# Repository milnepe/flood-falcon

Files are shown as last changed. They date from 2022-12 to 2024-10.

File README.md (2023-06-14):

# Flood Falcon & Flood Magnet
Arduino powered flood warning devices

Flood Magnet
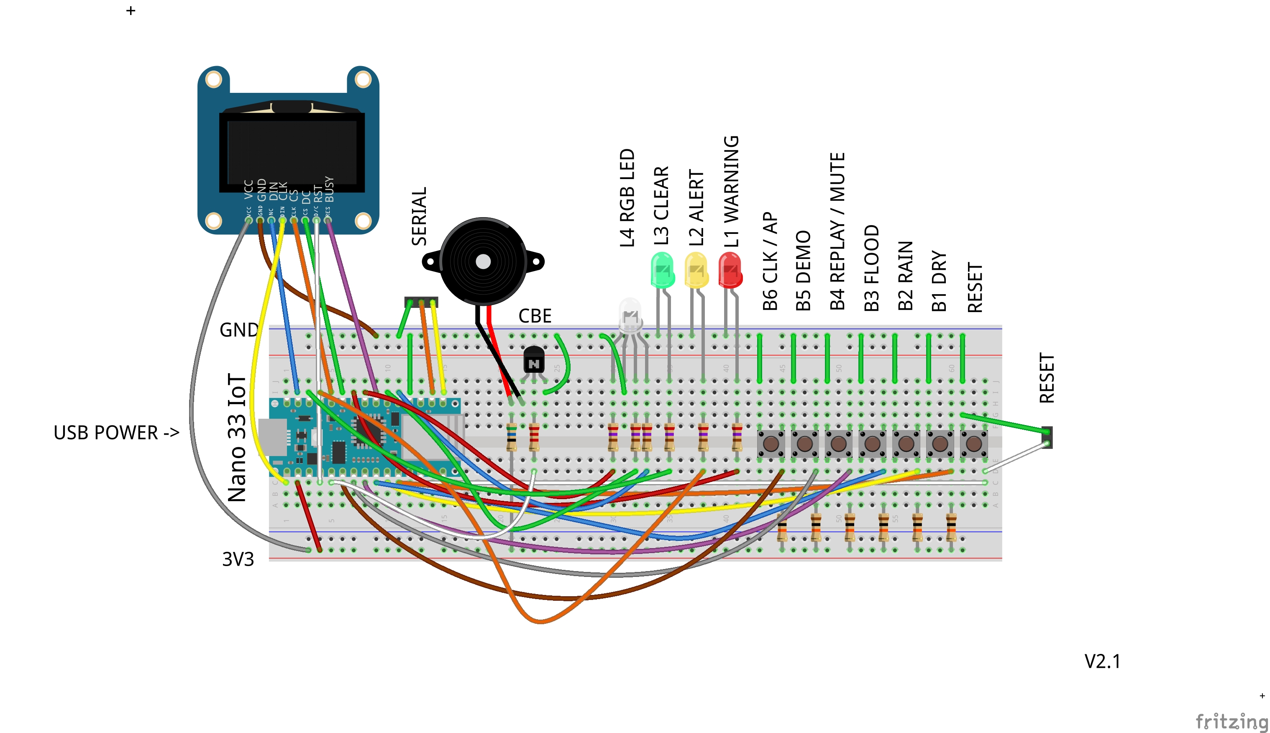
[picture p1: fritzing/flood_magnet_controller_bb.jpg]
Flood Magnet Circuit Diagram
.

## Introduction
The Environment Agency flood-monitoring API provides developers with access to near real time information covering:

- Flood warnings and flood alerts
- Flood areas which to which warnings or alerts apply
- Measurements of water levels and flows
- Information on the monitoring stations providing those measurements

Water levels and flows are regularly monitored, usually every 15 minutes. However, data is transferred back to the Environment Agency at various frequencies, usually depending on the site and level of flood risk. Transfer of data is typically once or twice per day, but usually increases during times of heightened flood risk.

These APIs are provided as open data under the Open Government Licence with no requirement for registration. If you make use of this data please acknowledge this with the following attribution statement:

"this uses Environment Agency flood and river level data from the real-time data API (Beta)"

## Getting your flood warning area
This is the easiest way to find out your flood area but there needs to be an alert or warning at the time:

You can get all the flood warnings in the UK in you browser by visiting the following URL:
[Flood alerts and warnings](https://check-for-flooding.service.gov.uk/alerts-and-warnings)

Click on the warning you are interested in for example Keswick Campsite:
[https://check-for-flooding.service.gov.uk/target-area/011FWFNC6KC](https://check-for-flooding.service.gov.uk/target-area/065WAF441)

The last part of the URL above is the flood warning area code in this example it is 011FWFNC6KC

If there is no flood warning for your area you can find the url from your Lat / Long coordinates.
For example Witney in Oxfordshire has lat: 51.7859° N, long: 1.4851° W
North is positive, West is negative.

Put these into the following URL 

http://environment.data.gov.uk/flood-monitoring/id/floodAreas?lat=y&long=x&dist=d

Where: y is the lat, x is the long and d is the distance in km from your location. Start with close distances and use larger values if you don't get any results.

So for Witney the URL is (Note the negative W coordinate):
https://environment.data.gov.uk/flood-monitoring/id/floodAreas?lat=51.7859&long=-1.4851&dist=0.5

Paste this into a browser and you will get a list of possible Flood Areas. Here's the result for Witney:
```
  "items" : [ { 
    "@id" : "http://environment.data.gov.uk/flood-monitoring/id/floodAreas/061FWF10Witney" ,
    "county" : "Oxfordshire" ,
    "description" : "River Windrush at Witney and Ducklington down to and including Hardwick" ,
    "eaAreaName" : "Thames" ,
    "floodWatchArea" : "http://environment.data.gov.uk/flood-monitoring/id/floodAreas/061WAF10Windrush" ,
    "fwdCode" : "061FWF10Witney" ,
    "label" : "River Windrush at Witney and Ducklington" ,
    "lat" : 51.75773 ,
    "long" : -1.45314 ,
    "notation" : "061FWF10Witney" ,
    "polygon" : "http://environment.data.gov.uk/flood-monitoring/id/floodAreas/061FWF10Witney/polygon" ,
    "quickDialNumber" : "171073" ,
    "riverOrSea" : "River Windrush"
  }
  , { 
    "@id" : "http://environment.data.gov.uk/flood-monitoring/id/floodAreas/061WAF10Windrush" ,
    "county" : "Gloucestershire, Oxfordshire" ,
    "description" : "River Windrush from Bourton to Newbridge including Burford, Asthall, Minster Lovell, Crawley, Witney, Ducklington, Rack End and Standlake" ,
    "eaAreaName" : "Thames" ,
    "fwdCode" : "061WAF10Windrush" ,
    "label" : "River Windrush from Bourton to Newbridge" ,
    "lat" : 51.82888 ,
    "long" : -1.65351 ,
    "notation" : "061WAF10Windrush" ,
    "polygon" : "http://environment.data.gov.uk/flood-monitoring/id/floodAreas/061WAF10Windrush/polygon" ,
    "quickDialNumber" : "171075" ,
    "riverOrSea" : "River Windrush"
  }
...
```
Use the "description" key to find the nearest area to you and then take the "@id" url for that area. For example:
"@id" : "http://environment.data.gov.uk/flood-monitoring/id/floodAreas/061FWF10Witney"

Now take the last part of the "@id" url which is the key for that area, in this case "061FWF10Witney"

Copy and paste the key into the magnet_config.h file:
```
// Your flood area code from Gov.co.uk Flood Warning Service
#define AREA_CODE "061FWF10Witney"
```

## Testing
You can test the API for your flood area by making a request in your browser to the following URI:
http://environment.data.gov.uk/flood-monitoring/id/floods/{your-flood-area-code}

So in the example above for the Witney use this URI:
[https://check-for-flooding.service.gov.uk/target-area/061FWF10Witney](https://check-for-flooding.service.gov.uk/target-area/061FWF10Witney)

This will return a JSON object with all the flood information for that area.

## API Documentation:
[Flood API](http://environment.data.gov.uk/flood-monitoring/doc/reference#flood-warnings)

## Falcon display
The Falcon / Magnet polls the API at the frequency you set and it receives the API response and displays the following data:

An icon representing the flood warning which may be at one of four possible severity levels - derived from the severityLevel:

Level	Name				    Meaning
1. Severe Flood Warning		    Severe Flooding, Danger to Life.
2. Flood Warning			    Flooding is Expected, Immediate Action Required.
3. Flood Alert                  Flooding is Possible, Be Prepared.
4. Warning no Longer in Force   The warning is no longer in force

The severity level description - derived from severity

The update date / time - derived from timeRaised (The date and time the warning was last reviewed. Usually (but not always) this leads to a change in the message or severity)

## Configuration
User config is in "falcon_config.h" or "magnet_config.h" Add your WiFi details and Flood Area there.

Audio clips are in ./audio - connect your sound board to your PC and copy the clips to the mounted drive.

## Demo Mode
Hold down the Demo button and press the Reset button to enter Demo Mode. Press Reset again to exit back to Standard Mode.

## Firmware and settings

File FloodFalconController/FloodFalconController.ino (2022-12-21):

/*
  Arduino Nano 33 IoT client for Gov.co.uk Flood Warning Service

  Install the following libraries using the Arduino Libary Manager:
  Arduino WiFiNINA https://github.com/arduino-libraries/WiFiNINA
  Benoît Blanchon ArduinoJson https://arduinojson.org/
  Evert-arias EasyButton https://github.com/evert-arias/EasyButton
  Adafruit Soundboard https://github.com/adafruit/Adafruit_Soundboard_library
  Adafruit PWM Servo Driver https://github.com/adafruit/Adafruit-PWM-Servo-Driver-Library

  Author: Peter Milne
  Date: 28 Nov 2022

  Copyright 2022 Peter Milne
  Released under GNU GENERAL PUBLIC LICENSE
  Version 3, 29 June 2007
*/

#include <SPI.h>
#include <WiFiNINA.h>
#include <ArduinoJson.h>
#include <EasyButton.h>
#include "FloodFalcon.h"
#include "FloodFalconDisplay.h"

const char* soft_version = "0.2.1";

#define SERVO 0        // Flapping servo
#define SERVO_FREQ 50  // Analog servos run at ~50 Hz

#define SFX_RST 4  // Sound board RST pin

// Flood warning data
static floodWarning warning;

WiFiClient client;

// Servo board - default address 0x40
Adafruit_PWMServoDriver pwm = Adafruit_PWMServoDriver();

// Sound board connected to Serial1 - must be set to 9600 baud
Adafruit_Soundboard sfx = Adafruit_Soundboard(&Serial1, NULL, SFX_RST);

FloodFalcon myFalcon = FloodFalcon(&sfx, &pwm, &warning);

FloodFalconDisplay epd = FloodFalconDisplay(&myFalcon);

int status = WL_IDLE_STATUS;
boolean updateDisplayFlag = false;
unsigned long lastReconnectAttempt = 0;
boolean playBackFlag = false;

// Define pins
const int wifiLed = 10;  // Optional debug LED (Green - On if connected)
const int rButton = 2;
const int lButton = 3;
const int dButton = 9;

EasyButton rightButton(rButton);  // RH button
EasyButton leftButton(lButton);   // LH button
EasyButton demoButton(dButton);   // External demo button

int demo_state = NONE;

void setup() {
  pinMode(wifiLed, OUTPUT);
  digitalWrite(wifiLed, LOW);

  // Initialize Serial Port
  Serial.begin(115200);
  while (!Serial) {
    ;  // wait for serial port to connect. Needed for native USB port only
  }
  delay(2000);

  // Serial 1 used for sound board at 9600 baud
  Serial1.begin(9600);
  while (!Serial1) {
    ;  // wait for serial port to connect
  }
  Serial.print("Starting client version: ");
  Serial.println(soft_version);

  Serial.println("Serial1 attached");

  // Initialize buttons
  rightButton.begin();
  rightButton.onPressed(playback);        // Short press triggers playback
  rightButton.onPressedFor(2000, audio);  // Long press toggles audio
  leftButton.begin();
  leftButton.onPressed(demo);  // Short press for demo
  demoButton.begin();
  demoButton.onPressed(demo);  // Short press external button for demo
  // Press reset button (middle) to exit demo

  // Setup display and show greeting
  epd.initDisplay();
  epd.showGreeting();

  // Init servo
  pwm.begin();
  pwm.setOscillatorFrequency(27000000);
  pwm.setPWMFreq(SERVO_FREQ);  // Analog servos run at ~50 Hz updates
  delay(1000);

  myFalcon.init(SERVO, WINGS_DOWN);  // Set statrting posture
  myFalcon.doAction(epd.audioOn);    // Trigger intro action

  leftButton.read();
  demoButton.read();
  if (leftButton.isPressed() || demoButton.isPressed()) {
    epd.demoOn = true;
  }

  delay(12000);
}

void loop() {
  // Continuously update the button states
  rightButton.read();
  leftButton.read();
  demoButton.read();

  if (!epd.demoOn) {  // Standard mode
    if (WiFi.status() != WL_CONNECTED) {
      // Connect wifi if it's not connected
      digitalWrite(wifiLed, LOW);
      epd.wifiOn = false;
      reconnectWiFi();
      delay(2000);
      if (WiFi.status() == WL_CONNECTED) {
        digitalWrite(wifiLed, HIGH);
        epd.wifiOn = true;
        Serial.println("Wifi connected...");
      }
      doUpdate();  // Initial update
    }
    unsigned long now = millis();
    if ((now - lastReconnectAttempt > ALERT_INTERVAL) || (updateDisplayFlag) || (playBackFlag)) {
      updateDisplayFlag = false;
      playBackFlag = false;

      doUpdate();
      lastReconnectAttempt = now;
    }
  } else {  // Demo mode - reset to exit so everything re-initialises
    doDemo();
  }
}

void doUpdate() {
  getData();
  myFalcon.updateState();
  myFalcon.doAction(epd.audioOn);
  epd.updateDisplay();
  printData();
}

void doDemo() {
  warning.severityLevel = demo_state;
  myFalcon.updateState();
  epd.updateDisplay();
  myFalcon.doAction(epd.audioOn);


  switch (demo_state) {
    case NONE:
      demo_state = FLOOD_ALERT;
      break;
    case SEVERE_FLOOD_WARNING:
      demo_state = NO_LONGER;
      break;
    case FLOOD_WARNING:
      demo_state = SEVERE_FLOOD_WARNING;
      break;
    case FLOOD_ALERT:
      demo_state = FLOOD_WARNING;
      break;
    case NO_LONGER:
      demo_state = NONE;
      break;
    default:
      break;
  }
  delay(DEMO_INTERVAL);  // Delay between state change
}

int reconnectWiFi() {
  // WL_IDLE_STATUS     = 0
  // WL_NO_SSID_AVAIL   = 1
  // WL_SCAN_COMPLETED  = 2
  // WL_CONNECTED       = 3
  // WL_CONNECT_FAILED  = 4
  // WL_CONNECTION_LOST = 5
  // WL_DISCONNECTED    = 6

  WiFi.disconnect();  // Force a disconnect
  delay(1000);
  // Creds from arduino_secrets.h
  WiFi.begin(SECRET_SSID, SECRET_PASS);
  return WiFi.status();
}

void getData() {
  // Connect to host
  Serial.println("Connecting to environment.data.gov.uk");
  if (!client.connect("environment.data.gov.uk", 80)) {
    Serial.println("Failed to connect to server");
    return;
  }

  // Send HTTP request
  client.println("GET /flood-monitoring/id/floodAreas/" AREA_CODE
                 " HTTP/1.0");
  client.println("Host: environment.data.gov.uk");
  client.println("Connection: close");
  client.println();

  // Check status code
  char status[32] = { 0 };
  client.readBytesUntil('\r', status, sizeof(status));
  // should be "HTTP/1.0 200 OK"
  if (memcmp(status + 9, "200 OK", 6) != 0) {
    Serial.print("Unexpected HTTP status");
    Serial.println(status);
    client.stop();
    return;
  }

  // Skip response headers
  client.find("\r\n\r\n");

  // Stream& input;
  StaticJsonDocument<128> filter;

  // Filter data objects so the response fits into memory
  JsonObject filter_items = filter.createNestedObject("items");
  filter_items["currentWarning"]["severityLevel"] = true;
  filter_items["currentWarning"]["floodAreaID"] = true;
  filter_items["currentWarning"]["timeRaised"] = true;

  StaticJsonDocument<1024> doc;

  DeserializationError error = deserializeJson(doc, client, DeserializationOption::Filter(filter));

  if (error) {
    Serial.print("deserializeJson() failed: ");
    Serial.println(error.c_str());
    return;
  }

  // Update warning struct
  warning.severityLevel = doc["items"]["currentWarning"]["severityLevel"];                                               // 3
                                                                                                                         //warning.severityLevel = 1; // mock level
  if (warning.severityLevel) {                                                                                           // only update these items if the level is not zero
    memcpy(warning.flood_area_id, doc["items"]["currentWarning"]["floodAreaID"].as<const char*>(), FLOOD_AREA_LEN - 1);  // "Tributaries between Dorchester and ...

    memcpy(warning.time_raised, doc["items"]["currentWarning"]["timeRaised"].as<const char*>(), DATESTR_LEN - 1);  // "2022-12-19T15:20:31"
    for (int i = 0; i < DATESTR_LEN; i++) {
      if (warning.time_raised[i] == 'T') {
        warning.time_raised[i] = ' ';
      }
    }
  }
  // Close the connection to the server
  client.stop();

  Serial.println("Flood data received!");
}

// Button callbacks
void playback() {
  Serial.println("Playback button pressed!");
  playBackFlag = true;
}

void audio() {
  Serial.println("Audio button pressed!");
  epd.audioOn = !epd.audioOn;
  updateDisplayFlag = true;
}

void demo() {
  Serial.println("Demo button pressed!");
  epd.demoOn = true;
}

void printData() {
  Serial.print("Flood Area: ");
  Serial.println(warning.flood_area_id);

  Serial.print("Warning Level: ");
  Serial.println(warning.severityLevel);

  Serial.print("Time Raised: ");
  Serial.println(warning.time_raised);
}

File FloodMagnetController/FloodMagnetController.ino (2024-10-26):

/*
  Arduino Nano 33 IoT client for Gov.co.uk Flood Warning Service

These APIs are provided as open data under the Open Government Licence with no requirement for registration.
If you make use of this data please acknowledge this with the following attribution statement:

"this uses Environment Agency flood and river level data from the real-time data API (Beta)"

  Install the following libraries using the Arduino Libary Manager:
  Arduino WiFiNINA https://github.com/arduino-libraries/WiFiNINA
  Benoît Blanchon ArduinoJson https://arduinojson.org/
  Evert-arias EasyButton https://github.com/evert-arias/EasyButton
  Waveshare EDP2in9 https://github.com/waveshareteam/e-Paper/tree/master/Arduino/epd2in9_V2

  Author: Peter Milne
  Date: 22 March 2023

  Copyright 2022 Peter Milne
  Released under GNU GENERAL PUBLIC LICENSE
  Version 3, 29 June 2007
*/

#include <EasyButton.h>
#include "FloodAPI.h"
#include "FloodMagnetDisplay.h"
#include "led.h"
#include "buzzer.h"

// Button connections
#define B1_PIN 21
#define B2_PIN 20
#define B3_PIN 19
#define B4_PIN 18
#define B5_PIN 17
#define B6_PIN 16

modes mode = STD_MODE;

const char* soft_version = "0.5.2";

FloodAPI myFloodAPI = FloodAPI();

FloodMagnetDisplay epd = FloodMagnetDisplay(&myFloodAPI);

// int status = WL_IDLE_STATUS;

EasyButton button1(B1_PIN);
EasyButton button2(B2_PIN);
EasyButton button3(B3_PIN);
EasyButton button4(B4_PIN);
EasyButton button5(B5_PIN);
EasyButton button6(B6_PIN);

void setup() {
  led_init();
  buzzer_init();

  // Initialize Serial Port
  Serial.begin(115200);
  // while (!Serial) {
  //   ;  // wait for serial port to connect. Needed for native USB port only
  // }
  delay(2000);

  Serial.print("Starting client version: ");
  Serial.println(soft_version);

  // Initialize buttons
  button1.begin();
  button1.onPressed(dry);
  button2.begin();
  button2.onPressed(rain);  // Place holder
  button3.begin();
  button3.onPressed(flood);  // Place holder
  button4.begin();
  button4.onPressed(replay);
  button4.onPressedFor(2000, buzzer_off);  // Cancel buzzer
  button5.begin();
  button6.begin();
  button6.onPressed(clock_sync_ap_mode);  // Place holder

  // Setup display and show greeting
  epd.initDisplay();
  epd.showGreeting();

  myFloodAPI.init();

  // Hold down B5 while pressing reset to enter demo mode
  // Press reset to exit back to standard mode
  if (button5.isPressed()) {
    mode = DEMO_MODE;
    rgb_colour(RED);
    Serial.println("Starting demo mode...");
    doDemo();
  }
  delay(3000);
}

void loop() {
  // Continuously update the button states
  button1.read();
  button2.read();
  button3.read();
  button4.read();
  // button5.read(); Read only in setup
  button6.read();

  if (WiFi.status() != WL_CONNECTED) {  // Connect wifi
    delay(5000);
    rgb_colour(RED);
    epd.wifiOn = false;
    reconnectWiFi();
    if (WiFi.status() == WL_CONNECTED) {
      rgb_colour(GREEN);
      epd.wifiOn = true;
      Serial.println("Wifi connected...");
      doUpdate();  // Initial update
    }
    else {
      epd.connectionError();
    }
  }
  unsigned long now = millis();
  static unsigned long lastApiAttemp = 0;
  if (WiFi.status() == WL_CONNECTED)  {
    if ((now - lastApiAttemp > ALERT_INTERVAL) || (mode == REPLAY_MODE)) {
      mode = STD_MODE;  // Clear replay
      doUpdate();
      lastApiAttemp = now;
    }
  }
}

void doUpdate() {
  int result = myFloodAPI.getData();
  if (result) {
    myFloodAPI.updateState(myFloodAPI.warning.severityLevel);
    epd.updateDisplay();
    printData();
  } 
  else {
    epd.apiError();
  }
}

void doDemo() {
  epd.demoOn = true;
  while (1) {
    button1.read();
    button2.read();
    button3.read();
    button4.read();
    // button5.read(); Read only in setup
    button6.read();
    unsigned long now = millis();
    static unsigned long lastUpdate = 0;
    if (now - lastUpdate > DEMO_INTERVAL) {
      buzzer_off();
      myFloodAPI.demo(DEMO_MODE);
      epd.updateDisplay();
      lastUpdate = millis();
    }
  }
}

int reconnectWiFi() {
  // WL_IDLE_STATUS     = 0
  // WL_NO_SSID_AVAIL   = 1
  // WL_SCAN_COMPLETED  = 2
  // WL_CONNECTED       = 3
  // WL_CONNECT_FAILED  = 4
  // WL_CONNECTION_LOST = 5
  // WL_DISCONNECTED    = 6

  WiFi.disconnect();  // Force a disconnect
  delay(1000);
  WiFi.begin(SECRET_SSID, SECRET_PASS);
  Serial.print("Wifi status: ");
  Serial.println(WiFi.status());
  return WiFi.status();
}

// Button callbacks
void dry() {
  Serial.println("B1 button pressed...");
  bip();
}

void rain() {
  Serial.println("B2 button pressed...");
  bip();
}

void flood() {
  Serial.println("B3 button pressed...");
  bip();
}

void replay() {
  Serial.println("B4 button pressed...");
  mode = REPLAY_MODE;
  bip();
}

void buzzerOff() {
  Serial.println("B4 button held...");
  buzzer_off();
}

void clock_sync_ap_mode() {
  Serial.println("B6 button pressed...");
  bip();
}

// Debug output
void printData() {
  Serial.print("Flood Area: https://check-for-flooding.service.gov.uk/target-area/");
  Serial.println(myFloodAPI.warning.flood_area_id);

  Serial.print("Warning Level: ");
  Serial.println(myFloodAPI.warning.severityLevel);

  Serial.print("Time Raised: ");
  Serial.println(myFloodAPI.warning.time_raised);
}

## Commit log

2023-03-22 Remove servo code
2023-03-22 Remove sound board code
2023-03-23 Update buttons
2023-03-25 Add more LEDs
2023-03-25 Add Flood Magnet circuit diagram
    [flood_magnet_controller.fzz]
2023-03-26 Enable buttons
2023-03-26 Updated docs and circuit diagram
2023-04-22 Reasign LED's to PWM pins
    RGB blue channel is not pwm due to no of available pins
2023-04-22 Turn off buzzer in demo mode
    [FloodAPI.cpp, FloodMagnetController.ino]
2023-04-22 Update schematic
    [flood_magnet_controller.fzz]
2023-04-25 Change Fritzing to common cathode
    [flood_magnet_controller.fzz]
2023-05-01 Change LED to common cathode
2023-05-01 Add transistor
    [flood_magnet_controller.fzz]
2023-05-01 Mute buzzer on B4
    [FloodAPI.cpp, FloodMagnetController.ino]
2023-05-01 Bump firmware & schematic versions
    [flood_magnet_controller.fzz]
2023-05-05 Update component ids
    [flood_magnet_controller.fzz]
2023-05-05 Added reset jumper J4
    [flood_magnet_controller.fzz]
2023-06-16 Remove PWM on red, amber, green LEDs
2024-10-26 Add API error display
    [FloodAPI.cpp, FloodMagnetController.ino]
